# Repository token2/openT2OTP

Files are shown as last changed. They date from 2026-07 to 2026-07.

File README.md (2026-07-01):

<p align="center">
  openT2OTP
</p>

# openT2OTP — open-source programmable TOTP hardware token

An open-source **firmware + hardware reference** for a self-contained, NFC-programmable
TOTP hardware token: a small device with a segment LCD that shows a rotating
6-digit code, keeps time for 5–8 years on a coin cell (depending on model), and is provisioned over NFC using the
documented Token2 programmable-token wire protocol. Any host that implements the
protocol can provision it; the open [`token2_config.py`](https://github.com/token2/token2_config.py)
tool is one such host. The same functionality also exists as a part of the  [`keyroost`](https://github.com/framefilter/keyroost) project 
and Token2 [`NFC Burner apps`](https://www.token2.swiss/site/page/mobile-nfc-burner-apps-for-the-second-generation-single-profile-token2-programmable-tokens) for Android and iOS (to be open sourced soon).

This is mainly the **actual firmware core our original programmable TOTP tokens run
on**, and only partially a reconstruction (the original code was less elegant, we tidyed it up a bit). 
We've decided to open-source it because there is nothing to hide in how a TOTP token works: 
the security of TOTP rests on the secret seed, not on obscurity of the device, so opening the design costs nothing
and lets anyone audit, learn from, or build on it.

### A little history

This code has a long, stable lineage. The core was **finalized in 2020** and has
run our programmable tokens ever since. It has changed very little since — the
**most recent change was in 2025**, when we removed the lockout that triggered on
a wrong customer key (the handshake now simply requires re-challenging rather than
locking; see [`docs/SECURITY.md`](docs/SECURITY.md)). What's published here is
**exactly the core our current hardware runs** — same protocol, same crypto, same
behavior.
Initially, the tokens were only allowing programming the seed, as we used a regular RTC.
But later on,when the RTC with the possibility to adjust its counter became possible to source,
we managed to make programmable tokens with [`time sync`](TIMESYNC.md).

**About the name.** "openT2OTP" is the name we chose *for the open-source release*.
Internally, this firmware was developed and shipped under a different codename; we
picked a plain, descriptive public name rather than carry the internal one over. So
if the code, comments, or history feel like they predate the "openT2OTP" label —
they do. The name is new; the core is not.

---

## ⚠️ Read this first: TOTP is not phishing-resistant

**TOTP (the 6-digit code) does not protect you from phishing.** A convincing fake
login page can ask for your code and replay it to the real site within the 30-second
window. The code has no idea *which* website it's being typed into, so it can't tell
a real site from a fake one.

If you need real phishing resistance, **use a FIDO2 / WebAuthn security key instead.**
FIDO2 cryptographically binds each login to the real site's origin, so a phished
credential is useless to an attacker. Token2 also open-sources FIDO2 work — prefer
that for any account that supports security keys.

Use this TOTP token when a service only supports TOTP, or as a convenient second
factor where you accept the phishing trade-off. It is **not** a substitute for a
FIDO2 key.

See [`docs/SECURITY.md`](docs/SECURITY.md) for the full threat model.

---

## What's in here

```
firmware/     portable C firmware (protocol + SM4 + TOTP + segment-LCD driver)
hardware/     LCD wiring, BOM, PCB floorplan, antenna & casing notes
docs/         protocol reference, security model, porting guide
```

- **Firmware** — implements the device side of the Token2 single-profile TOTP
  wire protocol (the ISO 7816 APDUs, SM4 handshake, MAC, seed and config writes),
  plus RFC 6238 TOTP generation and a segment-LCD display driver. It interoperates
  with any conformant host; hardware-agnostic C, ported by filling in a small HAL.
- **Hardware** — a reference design built around an MCU with an integrated
  segment-LCD controller and RTC, an NFC front-end, and a coin cell. Keyfob-dongle
  form factor as the main target, card as a documented variation.

The casing and board outline here are **deliberately our own** — this is a
functional reference, not a clone of anyone's industrial design.

## Verified, not just written

Every cryptographic and framing claim in the firmware is checked against a
published test vector or an exact round-trip:

```
cd firmware
make test     # full Token2 wire-protocol session       -> ALL TESTS PASSED
make kat      # SM4 vs GM/T 0002 known-answer test        -> PASS
make totp     # TOTP vs RFC 6238 test vectors             -> PASS
make seed     # seed framing round-trips (all 1..63 lens) -> PASS
make slcd     # segment-LCD driver renders digits         -> PASS
make all      # everything
```

You need only a C compiler (`gcc`/`clang`) and `make`.

## Quick start

1. **Read the firmware** — start at [`firmware/README`](firmware/README.md) for the
   protocol implementation, then [`docs/PROTOCOL.md`](docs/PROTOCOL.md) for the wire
   format.
2. **Read the hardware reference** — [`hardware/HARDWARE.md`](hardware/HARDWARE.md)
   covers the LCD, wiring, BOM, and PCB design.
3. **Port to your target** — implement the HAL in
   [`docs/PORTING.md`](docs/PORTING.md) (RTC, NVM, RNG, LCD segment map).
4. **Provision a token** — use [`token2_config.py`](https://github.com/token2/token2_config.py) 
   over NFC/PC-SC to write a seed and configuration.

## On sourcing components

The BOM lists **mainstream, easy-to-source example parts** (a Microchip SAM L22
MCU, a standard NFC front-end, a transflective segment LCD, a CR2032). You can
build the reference with off-the-shelf parts from any distributor.

**We ordered components manufactured specifically for this code to run on** — the
exact parts our production tokens use. They're proven, but **not always easily
sourceable** (some are factory-tailored equivalents of a mainstream component).
Our **research suggests standard off-the-shelf components should work as well**, so
the BOM lists mainstream, buy-anywhere equivalents as examples, not requirements:
anything with an integrated segment-LCD controller, an RTC, and enough flash should
do. If small changes are needed to run on a particular off-the-shelf part, **we'll
update the design — and community updates, or even just reports of such
incompatibilities, are very welcome.**

## Board layout

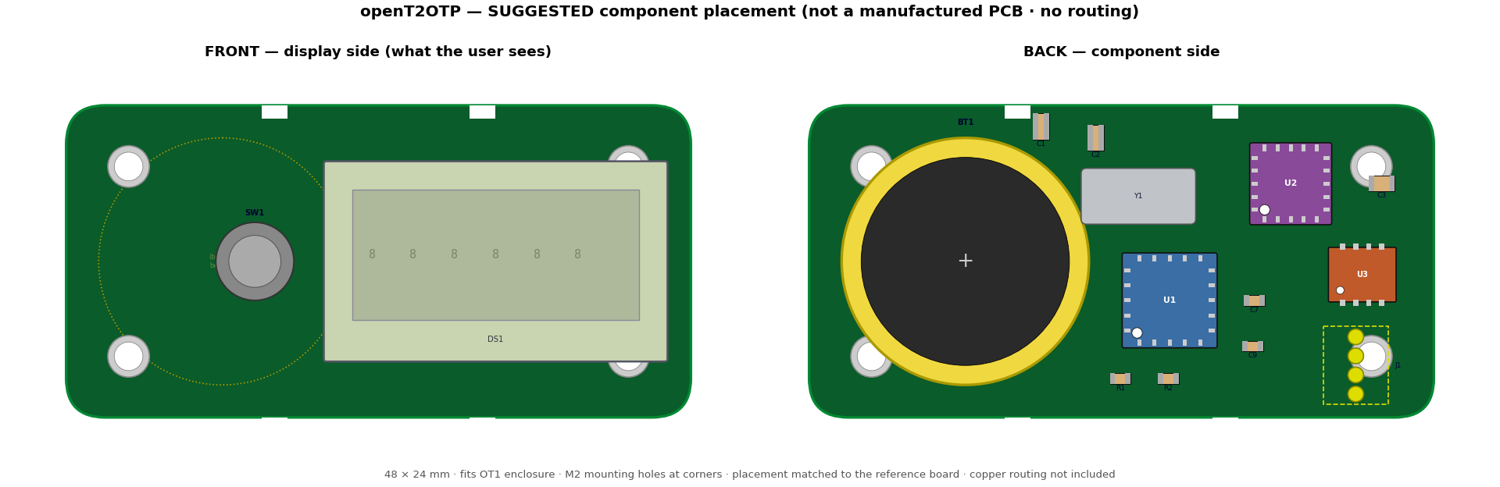
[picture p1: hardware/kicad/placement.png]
openT2OTP suggested component placement


*Suggested component placement — an illustration, not a manufactured PCB or a
routed board. See [`hardware/kicad/README.md`](hardware/kicad/README.md) for
what this is and isn't.*

## License

- **Firmware:** MIT — see [`LICENSE`](LICENSE).
- **Hardware documentation & design:** CERN-OHL-P v2 — see
  [`hardware/LICENSE-HARDWARE`](hardware/LICENSE-HARDWARE).

## Contributing

Issues and PRs welcome — see [`CONTRIBUTING.md`](CONTRIBUTING.md). Good first areas:
additional glass pin-maps, a routed KiCad PCB for the reference board, and reports
of any off-the-shelf components that need small tweaks to run the core (see the
sourcing note).

## Provenance

This is the **real device-side firmware from our programmable TOTP tokens**,
implementing the **Token2 single-profile programmable TOTP wire protocol**. The
protocol and a reference host are published openly at
[`token2_config.py`](https://github.com/token2/token2_config.py) (see its
`PROTOCOL.md`); that tool is one conformant host. The core here was finalized in
2020, last changed in 2025 (wrong-key lockout removed), and is what our current
hardware runs.

## P.S. Also available: programmable cards

The same openT2OTP firmware core also runs on our programmable TOTP **cards** — the
credit-card-format version of the token. From the code's point of view they are
identical: the same provisioning protocol, the same seed handling, the same one-time-code
generation. If you have read and trust the firmware here, it is the very same firmware on
the card.

The *hardware*, however, is a different story. A card packs the electronics into
ISO-7810 thickness using laminated inner layers, thermally bonded assembly, and custom
ultra-thin flat batteries — construction that requires specialised industrial equipment.
Unlike the keyfob reference in this repository, a card is **not something you can assemble
yourself**, and we don't publish it as a DIY design because it genuinely isn't one. The
open source here is the firmware; the card hardware is ours to manufacture.

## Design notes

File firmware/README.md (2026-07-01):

# Firmware — device-side TOTP token

> Part of the [openT2OTP](../README.md) repository. See the root README for the
> project overview and the important note that **TOTP is not phishing-resistant**
> (use FIDO2 for phishing resistance).

This is the **actual device-side firmware from our programmable TOTP tokens** —
a portable, hardware-agnostic implementation of the Token2 single-profile
programmable TOTP token **wire protocol**. Any host that speaks the protocol can
provision the device; the open `token2_config.py` is one such host, and its
`PROTOCOL.md` is the canonical spec this firmware implements. A host writes a seed
and configuration to the token over NFC/PC-SC; this firmware is what answers those
APDUs. The core was finalized in 2020 and is verified by host-side tests that
replay a full session and check the crypto against published test vectors.

> **Provenance & scope.** This is our real production core, now open-sourced —
> not a reconstruction. The "device SM4 key" in `PROTOCOL.md` is a fixed, publicly
> documented value (intentionally so — see `../docs/SECURITY.md`); anyone forking
> this for a *different* product who wants real device authentication should move
> to a per-device secret key. As-is, this is exactly what our tokens run.

## What it implements

Plain commands (CLA `0x80`, no auth):
- `0x41` get info — returns serial + on-device UTC time
- `0x4B/P1=08` get challenge — 8 random bytes
- `0xCE` auth finish — verifies `SM4(challenge ‖ 8 zero bytes)`

Secure commands (CLA `0x84`, 4-byte SM4-CBC-MAC required, auth required):
- `0xC5/P1=01` write seed — SM4-ECB body, 9797-1 padding, both the general and
  the 32-byte "extra pad block" framings
- `0xD4` write config — 19-byte plaintext TLV: display timeout, UTC clock set,
  HMAC algo (SHA1/SHA256), time step (30s/60s)

Behaviours from the spec: MAC header uses plain class `0x80` even for `0x84`
APDUs; `restricted_sync` clears the seed on config write; bad auth / locked key
returns `6983`; wrong length returns `6700`.

## Layout

```
include/  sm4.h  token2.h  token2_hal.h     public API + HAL contract
src/      sm4.c                             SM4 + protocol CBC-MAC (KAT-verified)
          token2.c                          APDU dispatcher (the firmware core)
          nfc_transport.c                   deploy shim for SE applet / MCU frontend
test/     mock_hal.c test_main.c kat.c      host tests
Makefile
```

## Build & test (host)

```
make test     # replays a full host session against the core -> ALL TESTS PASSED
make kat      # SM4 vs GM/T 0002 known-answer test -> PASS
```

The core (`src/sm4.c`, `src/token2.c`) has no host dependencies beyond the four
HAL functions in `token2_hal.h`. Cross-compile those two files with your target
toolchain and supply a real HAL.

## Porting: the HAL you must provide

| Function | Responsibility | On a secure element |
| --- | --- | --- |
| `hal_rtc_get/set` | UTC seconds, set by config cmd | external low-power RTC (SE usually has none) |
| `hal_nvm_read/write` | tamper-resistant store for seed+config | SE protected EEPROM/flash |
| `hal_rng` | 8-byte challenge | certified on-die TRNG (never a clock-seeded PRNG) |
| `hal_ct_memcmp` | constant-time compare | SE crypto-lib helper |

## Hardware recommendations

The protocol has three hard requirements that drive the part choice:
**(1) contactless ISO 14443-4 (NFC Type-4) card emulation answering raw APDUs
with no applet SELECT, (2) SM4** (the GB/T 32907 cipher — not AES), and
**(3) a timekeeping source** for TOTP.

### Important constraint: SM4 availability

Mainstream JavaCard/JCOP secure elements (e.g. NXP JCOP 4.5 on P71) expose
AES / 3DES / RSA / ECC / SHA through the JavaCard crypto API but **do not expose
SM4** as a standard primitive; JCOP lists AES, 3DES, RSA, ECC and Korean SEED,
not SM4. So on a certified SE you have two realistic routes:

- **A native SM4 execution path.** NXP JCOP 4.5 P71 ships *SecureBox*, a native
  C sandbox inside the secure enclave for exactly the algorithms the JavaCard
  API lacks. Compile `sm4.c` into a SecureBox module and call it from the
  applet. This keeps the key and cipher inside the certified boundary. Requires
  an NXP SecureBox NDA/toolchain (partners like Cryptnox do this commercially).
- **Software SM4 in the applet.** Run `sm4.c` as plain applet bytecode. Simplest
  to build; the seed still lives in SE-protected EEPROM, but the SM4 operation
  itself isn't hardware-accelerated or side-channel-hardened. Acceptable for a
  reference/interop token, not for a high-assurance product.

### Option 1 — Certified secure element (closest to the real product)

- **NXP JCOP 4.5 on P71 (SmartMX3)** — ARM SC300 + FAME3 crypto coprocessor,
  Java Card 3.0.5/3.1, GlobalPlatform 2.3.x, dual-interface (contact +
  contactless up to 848 kbit/s), EAL6+ class hardware, PUF-backed identity.
  Register your applet with the **default-selected** privilege so the card
  routes APDUs to it without a SELECT AID — that is what lets a host like `token2_config.py`
  talk to it directly, matching the "no applet SELECT" posture in the protocol.
  SM4 via SecureBox as above.
- **Infineon SLE78 / SECORA ID** or **Samsung S3K** are equivalent-class
  alternatives if you prefer their toolchains; same SM4 caveat applies.

Pros: real tamper resistance, certified TRNG, protected key store, exactly the
device category Token2 ships. Cons: NDA-gated SDKs, needs an external RTC.

### Option 2 — Secure MCU + NFC frontend (fastest to prototype, fully open)

- **MCU:** an Arm Cortex-M with on-chip AES/crypto and secure storage, e.g.
  **STM32L5 / U5** (TrustZone-M, on-chip RTC, low power) or **NXP LPC55S69**
  (TrustZone, PUF, casper crypto). The on-chip RTC satisfies requirement (3)
  directly; run `sm4.c` in software (cheap on M33).
- **NFC frontend in card-emulation:** **ST25DV** (dynamic NFC tag with I²C, if
  you drive the tag memory) or a full CE-capable controller like **NXP PN7160 /
  PN5180** or **ST ST25R3916** presenting an **ISO-DEP (14443-4)** endpoint.
  ISO-DEP is block-based (T=1); feed each deblocked APDU straight to
  `nfc_on_apdu()` — no `61 XX`/`6C XX` handling needed (that's only for T=0
  contact readers).

Pros: no NDA, open toolchain, on-chip RTC, easy to debug over the same PC/SC
path a conformant host uses. Cons: not certified tamper-resistant; a discrete secure
element (e.g. **ATECC608** / **NXP SE050** / **Microchip TA100**) can be added
over I²C to hold the seed if you want a protected key store — note those provide
AES/ECC, so SM4 still runs on the MCU.

### Option 3 — Add a dedicated secure element to Option 2

Pair the MCU with **NXP SE050** or **Microchip ATECC608B** purely as a protected
key/seed vault and TRNG source (map `hal_nvm_write` for the seed and `hal_rng`
to it), while SM4 and the APDU logic stay on the MCU. Good middle ground:
open toolchain, hardware-protected secrets.

## Deployment shim

`src/nfc_transport.c` shows the two integration points:
`nfc_on_activate()` (call at power-up → `token2_init()`) and
`nfc_on_apdu(cmd, len, resp, cap)` (call per received APDU). For an SE applet,
call `token2_process_apdu()` from `process(APDU)`; for an MCU, call it from your
ISO-DEP receive callback.

## Security notes (read before shipping anything)

- The device SM4 key is **fixed and public** in the protocol, so device
  authentication only proves the host knows a published constant — it is not a
  real secret. Any product reusing it has no meaningful anti-cloning or
  anti-tamper authentication at the protocol level. A real deployment should
  move to a per-device key and a challenge/response the attacker can't precompute.
- Keep the seed inside the secure boundary (SE EEPROM or a discrete SE); never
  expose a read-seed command (the protocol has none — preserve that).
- Use a certified TRNG for the challenge; a predictable challenge lets a
  recorded `SM4(challenge‖0)` be replayed.
```

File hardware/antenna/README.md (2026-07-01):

# NFC antenna — design, geometry & tuning

The token is read and provisioned over NFC at **13.56 MHz** (ISO 14443). The
antenna is a **PCB copper loop** around the board perimeter — no antenna "part"
in the BOM, only etched copper plus two tuning capacitors (C1/C2).

## Files here

| File | What it is |
| --- | --- |
| `coil.md` | Reference coil geometry for the keyfob outline (turns, width, spacing, keep-out). |
| `tune.py` | Calculator: given the measured loop inductance, prints the matching capacitance for 13.56 MHz. |

## Quick tune

```
# after measuring the fabricated coil (e.g. 2.5 uH):
python3 tune.py -L 2.5u
```

Fit the nearest C0G/NP0 E12 value across C1/C2, then trim on the bench against a
VNA resonance dip or by maximising reader read-range. Re-check with the shell
closed and battery fitted — both shift resonance.

## Rules that must hold

1. **No copper, no battery, no metal inside the loop** — it detunes the coil and
   kills read range. Battery goes on the back, outside the loop footprint.
2. **Via-stitch the corners** so top/bottom turns add in series.
3. **Keep the LCD zebra zone clear** of the coil.
4. **Symmetric terminals** back to C1/C2 near the NFC front-end.

## Vendor references

Start from your NFC front-end vendor's antenna design guide and tuning
spreadsheet (ST and NXP publish these for their 13.56 MHz front-ends) and adapt
the outline to the keyfob shape rather than computing the coil from scratch.

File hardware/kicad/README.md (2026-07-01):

# KiCad — reference schematic & netlist

This directory holds a **connectivity schematic** for the openT2OTP reference
board, generated from the documented design. It is not a routed PCB — it gives
you the correct components and nets so you can drop in real footprints and lay
out the board.

## Files

| File | What it is |
| --- | --- |
| `openT2OTP.kicad_sch` | Self-contained KiCad 7 schematic (symbols embedded; opens with no external libraries). Every component is a labeled block; nets are expressed as global labels. |
| `openT2OTP.net` | KiCad-format netlist — the electrical source of truth (27 nets, 0 dangling). |
| `gen_schematic.py` | The schematic generator. Edit the `COMPONENTS` and `NETS` tables and regenerate. |
| `openT2OTP.kicad_pcb` | KiCad 7 PCB with the **board outline, mounting holes, and component placement** sized to fit the OT1 enclosure. **Placement only — not routed** (see below). |
| `gen_pcb.py` | The PCB generator. Board geometry (48×24 mm, 4× M2 holes at ±19.2/±7.3 mm) is derived from the OT1 STEP enclosure. |
| `gen_gerber.py` | Exports the mechanical Gerber + drill (outline + mounting holes). |
| `gerbers/` | Fabricable **board-outline** Gerber (`Edge_Cuts.gbr`) and Excellon drill (`PTH.drl`). Copper layers are absent by design — route first. |
| `placement.png` | **Suggested placement diagram** (see below) — an illustration, not a manufactured PCB. |
| `draw_placement.py` | Renders `placement.png` from the `.kicad_pcb`. |

## About `placement.png` — read this so it isn't misunderstood

`placement.png` is a **suggested component-placement diagram**. It shows where each
part would sit on a 48×24 mm board that fits the OT1 enclosure, with the arrangement
matched to the real reference board (battery clip at one end, IC cluster at the
other, LCD and button on the front).

**It is a drawing, not a photograph of a real board, and not a fabricable PCB.**
Specifically:

- The component shapes (QFNs, coin cell, LCD, crystal) are **illustrations** drawn
  to approximate size, not real vendor footprints.
- There is **no copper routing** — no traces, no ground plane, no vias. A real board
  needs all of that, done in KiCad with real footprints and DRC.
- A **Gerber/PCB never contains components anyway** — Gerbers describe only the bare
  board (copper, mask, silk, drill). The chips you see on a physical board are placed
  after manufacturing and never appear in Gerber files. So a "PCB image with chips on
  it" only comes from a **3D render of a fully-routed board**, which is a later step.

Use this diagram to understand and communicate the layout. To get to a board that
looks like the reference hardware: assign real footprints in `openT2OTP.kicad_pcb`,
route it, run DRC, then use KiCad's 3D viewer for a populated render and export the
full Gerber set for fab.

## The PCB: what's real and what isn't

The `.kicad_pcb` and the `gerbers/` are **mechanically real and honest about their
limits**:

- **Real & fabricable now:** the 48×24 mm rounded board outline and the four M2
  mounting holes at the enclosure's boss positions (±19.2, ±7.3 mm). A fab can cut
  and drill this exact blank and it will fit the OT1 case. The outline Gerber is a
  closed, dimension-checked profile.
- **Real placement:** all 15 components from the netlist are placed with courtyards,
  overlap-checked, front/back split (LCD on the front face; MCU, NFC, secure
  element, crystal, coin cell, passives, SWD on the back).
- **NOT done — you must do this in KiCad:** copper routing, the ground pour, via
  stitching, and especially the **13.56 MHz antenna matching**. The perimeter loop
  on `F.Cu` is placeholder geometry; measure the fabricated coil and retune with
  `../antenna/tune.py`. Run DRC, then export the full copper/mask/silk/paste Gerber
  set for production. **Do not send the current state to fab as a finished board.**

## Regenerate

```
python3 gen_schematic.py > openT2OTP.kicad_sch   # schematic + netlist
python3 gen_pcb.py       > openT2OTP.kicad_pcb   # outline + holes + placement
python3 gen_gerber.py                            # mechanical gerbers -> gerbers/
```

The net table in `gen_schematic.py` is validated to have no single-pin
(dangling) nets. See `../PINMAP.md` for the human-readable pin assignment.

## How to take this to a board

1. Open `openT2OTP.kicad_sch` in KiCad 7+.
2. Replace each generic block with the real library symbol + footprint for your
   chosen part (SAM L22 TQFP64, ST25R3916 QFN32, SE050, the LCD glass zebra
   footprint, 0402/0603 passives, CR2032 holder).
3. Keep the nets identical to `openT2OTP.net`.
4. Lay out the PCB per `../HARDWARE.md` (keyfob floorplan) and
   `../antenna/coil.md` (perimeter antenna + keep-out).
5. Design your own board outline and silkscreen — see `../CASING.md`.

## What this is not

- The `.kicad_pcb` is **placement, not a routed board** — no copper traces, no
  ground pour, no tuned antenna. Routing and DRC are yours to do in KiCad.
- Not tied to specific footprints — symbols and placement blocks are generic by
  design, so the netlist stays valid whatever exact parts you source. Swap in real
  vendor footprints before routing.

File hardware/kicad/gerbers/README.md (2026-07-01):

# Gerbers — board outline + drill only

These files define the **mechanical** board only:

- `openT2OTP-Edge_Cuts.gbr` — the 48 x 24 mm rounded board outline (RS-274X).
- `openT2OTP-PTH.drl` — Excellon drill: 4 x M2 (2.2 mm) mounting holes at the
  OT1 enclosure boss positions (+/-19.2, +/-7.3 mm).

They let a fab cut and drill the correctly shaped blank that fits the OT1 case.
**Copper layers are intentionally absent** — the board is not yet routed. Route
it in KiCad from `../openT2OTP.kicad_pcb`, run DRC, then export the full Gerber
set (copper, soldermask, silk, paste) for production.

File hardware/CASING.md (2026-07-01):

# Casing & industrial design

The enclosure and board outline in this reference are **deliberately our own**.
This repository open-sources how a TOTP token *works* — the firmware, the wire
protocol handling, the electrical design — not any particular product's *look and
feel*. The industrial design (shell shape, button placement, silkscreen, colours,
proportions) is intentionally distinct from other vendors' tokens to avoid trading
on anyone's trade dress or design IP.

If you fork this, keep that separation in mind: reuse the electronics and firmware
freely under their licenses, but design your own housing rather than copying an
existing product's appearance.

## Reference form factor: keyfob dongle

Our main reference is a **keyfob dongle** with:
- a segment LCD window at one end,
- a single power/show button at the other,
- a key-ring tab on one side,
- a two-part snap or ultrasonically-welded shell.

Chosen because it's the most buildable: a rigid board with vertical room for a
replaceable coin-cell holder, a tactile button, and a generous perimeter antenna.
See [`HARDWARE.md`](HARDWARE.md) §0 for the dongle-vs-card trade-offs.

**Distinct design cues** (make your own choices — these are just ours):
- an asymmetric outline rather than a plain rounded rectangle,
- button and LCD arranged along the long axis,
- our own silkscreen pattern and wordmark placement.

## Card variation

A card variant is documented as a variation (same schematic, thinner stack-up,
printed antenna, sealed cell). If you build a card, again: use your own card
artwork and outline, not a copy of an existing product's card face.

## Mechanical checklist

- LCD window aligned to the glass active area; light pipe or plain window (no
  backlight needed for a transflective display).
- Button plunger reaches the PCB switch with the shell closed.
- Coin-cell access: a hatch for the keyfob (replaceable) or a sealed pocket for
  the card.
- Antenna keep-out respected inside the shell — no metal foils or coatings over
  the coil.
- Housing holds the LCD zebra strip under compression against the PCB pads.

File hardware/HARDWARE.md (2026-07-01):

# TOTP token — LCD, wiring, BOM & PCB design

This extends the device-side firmware with the **display and board design** for a
self-contained programmable TOTP token: a device that shows a 6-digit code on a
segment LCD, keeps time on a coin cell for 5–8 years (model-dependent), and is
provisioned over NFC by any host implementing the Token2 programmable-token
protocol.

The whole approach is modeled on how commercial tokens (and the open-source
Sensor Watch) actually do it: a **raw segment-LCD glass driven directly by an
MCU that has a built-in LCD controller** — no separate display driver, always-on
at microamps, years on one cell.

## 0. Form factor: keyfob dongle (main) vs card (variation)

This matches the real Token2 line, which ships both a **keyfob dongle** (the
C302 style) and a **card** token. Electrically they are the *same design* — 6-digit
segment LCD, one power/show button, coin-cell-class power, NFC programming with no
port. The only differences are mechanical: antenna size, battery, and rigidity.

**Main target: the keyfob dongle (C302-style).** It's the easier and more
prototype-friendly build:
- A normal **rigid FR-4 board (~1.6 mm)** with vertical room for a proper tactile
  button and a **user-replaceable CR2032 holder** on the back.
- A **larger perimeter antenna loop** → better NFC read range and easier tuning.
- A molded two-part case with a key-ring tab.

**Variation: the card.** Same schematic, harder mechanicals:
- Card body is ~0.8 mm, so it needs a **flex or ultra-thin rigid-flex PCB** and a
  **printed/embedded antenna** in a smaller area.
- Powered by a **soldered thin coin/pouch cell** (e.g. a thin CR-class cell), not
  a holder — which is why production card tokens are **sealed and disposable** when
  the battery is exhausted.
- Assembly is typically laminated rather than a snap case.

Everything below (MCU, LCD, firmware, BOM) is shared; the two "PCB design"
subsections at the end call out what changes for the card.

---

## 1. Why a segment LCD (not OLED / TFT / LED)

| Option | Idle current | Always-on | Fits a card | Verdict |
| --- | --- | --- | --- | --- |
| **Segment LCD (transflective TN)** | ~1–5 µA | yes | yes | **Chosen** |
| OLED | mA-class when lit | no | thick | too power-hungry |
| TFT | tens of mA + backlight | no | thick | far too power-hungry |
| LED 7-seg | mA even dimmed | no | yes | drains a coin cell in days |

A TOTP token must hold the display readable while sipping current from a CR2032
(~225 mAh). Only a reflective/transflective segment LCD does that. The trade-off
is that a segment LCD can only show fixed shapes — which is fine, we only need
digits 0–9.

At a segment-LCD idle draw of ~1–5 µA, a ~225 mAh CR2032 lasts on the order of
**5–8 years** (225 mAh / a few µA ≈ tens of thousands of hours), which is the
service life real programmable TOTP tokens quote. Exact life depends on the
model: display duty, how often the code is shown, the RTC/MCU sleep current, and
self-discharge of the cell. Lower-power sleep modes and a smaller display push
toward the upper end; a larger display or frequent button use toward the lower.

---

## 2. How the LCD wires to the MCU

A multiplexed segment LCD is a grid of **COM (backplane)** lines crossing
**SEG (segment)** lines. Each bar of each digit is one pixel that lights when its
COM/SEG intersection is driven. The MCU's SLCD peripheral generates the AC
drive waveforms (bias voltages, frame-inverted so there's **no net DC** — DC
permanently damages LCD glass).

For a **6-digit, 7-segment** display = 42 segments. With a common **1/4-duty**
glass:
- 4 COM lines
- ⌈42 / 4⌉ = **11 SEG lines**
- **15 MCU pins total**, all from the SLCD peripheral.

The glass does **not** solder to the board. It connects by either:
- a **zebra strip** (elastomeric connector) pressed between glass and PCB pads by
  the housing, or
- a **heat-seal FPC tail** bonded to the board.

Wiring summary:

```
SAM L22 SLCD pins  ──►  COM0..COM3      ─┐
                   ──►  SEG0..SEG10     ─┴─► zebra strip ─► LCD glass
LCD bias caps      ──►  CAPL/CAPH, VLCD reservoir caps (per datasheet)
```

The SAM L22 has an internal charge pump / bias generator, so the only external
LCD parts are a few small bias reservoir capacitors (the datasheet's LCD section
lists the exact values). No contrast pot, no driver IC.

**Segment-to-pin mapping** is defined by the *glass* datasheet: it gives a pinout
table listing, for every segment, which COM and SEG pin it sits on. You transcribe
that table into `hal_slcd_set_digit()` (in the firmware). The portable font and
digit logic live in `firmware/src/slcd.c`; only the COM/SEG bit placement is board-specific.

---

## 3. Recommended hardware

### 3.1 MCU — the linchpin

**Microchip SAM L22 (ATSAML22N18A)** — 32-bit Cortex-M0+, and critically it
integrates:
- a **segment-LCD controller** (up to 48 SLCD pins / 320 segments — far more than
  our 15),
- a **32-bit RTC** (the TOTP time base),
- **AES**, ample flash/SRAM,
- ultra-low-power sleep modes measured in **µA**.

This is the same class of part (SAM L22) used in ultra-low-power always-on
segment-LCD designs that run for years on a coin cell. It collapses MCU + LCD
driver + RTC into one chip, which is exactly what you want in a token.

> SM4 note (from the protocol work): the SAM L22's AES block does **not** do SM4,
> so the SM4 used by the Token2 protocol runs in software (`firmware/src/sm4.c`). It's
> cheap on an M0+ and only runs during the rare NFC programming session, not on
> every display refresh.

### 3.2 Display

A **6-digit 7-segment transflective TN glass**, custom or catalog. Suppliers:
Good Display (e.g. GDC-series TN transflective segment glass), Crystalfontz,
Truly, Varitronix. For a first prototype, a catalog 6-digit static/multiplexed
TN glass with a zebra connector is the fastest path; for production you order a
custom glass with your exact digit layout and any icons (battery, lock).

### 3.3 NFC front-end

The host talks ISO 14443-4 (NFC Type-4). Two routes:
- **Discrete NFC controller in card-emulation:** NXP PN7160 / PN5180, or ST
  ST25R3916. These present a proper ISO-DEP endpoint; you feed each received APDU
  straight into `token2_process_apdu()`.
- **Passive NFC tag front-end with I²C:** ST ST25DV — simpler and lower power,
  but you drive the APDU exchange through its mailbox/energy-harvest path.

For a battery token that must answer live APDUs, a controller like the
**ST25R3916** or **PN7160** is the clean choice.

### 3.4 Optional secure element (seed vault)

The seed should live in tamper-resistant storage. Add **NXP SE050** or
**Microchip ATECC608B** over I²C purely to hold the seed and serve the TRNG;
SM4 and APDU logic stay on the MCU. (These provide AES/ECC, not SM4 — that's
fine, they're a vault, not the protocol engine.)

**This is what makes "the seed can't be extracted" true.** The wire protocol is
already write-only (no read-seed command), but on a bare MCU the seed still sits in
on-die flash and is recoverable by a determined attacker. Put it in an SE and it
never leaves the SE's protected store. Best practice: inject the seed into the SE
**marked non-exportable** and run the HMAC **inside** the SE, so the seed is never
present in MCU RAM — even compromised firmware can't read it. Our production tokens
do exactly this. See [`docs/SECURITY.md`](../docs/SECURITY.md) → "Seed protection"
for the storage-vs-extraction table (Pico/plain flash = assume extractable; SE with
non-exportable key = not extractable). Omit the SE for a hobby/demo build; include
it for anything resembling a product.

### 3.5 Timekeeping

The SAM L22 RTC runs from a **32.768 kHz watch crystal** (e.g. Epson FC-135 or
Abracon ABS07). This sets TOTP accuracy — use a crystal with a low ppm rating so
codes don't drift between programmings.

### 3.6 Power

**Keyfob (main):** **CR2032** (3 V, ~225 mAh) in a **back-side replaceable
holder**, with decoupling caps. At a few µA average the token runs about **5–8
years** on one cell (model-dependent — see §1), and the user can swap the cell.

**Card (variation):** a **soldered thin coin/pouch cell** in the ~0.8 mm budget;
no holder, so the card is sealed and replaced (not serviced) at end of life.

---

## 4. Bill of materials (single prototype)

Reference prices are indicative single-unit/small-qty (USD) and will drop sharply
at volume. Always confirm live pricing and stock at a distributor.

| # | Ref | Part | Function | Example MPN | ~Qty | ~Unit $ |
| --- | --- | --- | --- | --- | --- | --- |
| 1 | U1 | MCU w/ SLCD+RTC | brains, LCD drive, timekeeping | ATSAML22N18A | 1 | 4–6 |
| 2 | DS1 | 6-digit 7-seg TN LCD glass | display | Good Display GDC-series (or custom) | 1 | 2–5 |
| 3 | — | Zebra strip / heat-seal | glass-to-PCB contact | elastomeric connector | 1 | 0.3–1 |
| 4 | U2 | NFC controller | ISO 14443-4 card emulation | ST ST25R3916 / NXP PN7160 | 1 | 2–4 |
| 5 | U3 | Secure element (optional) | seed vault + TRNG | NXP SE050 / Microchip ATECC608B | 1 | 0.5–2 |
| 6 | Y1 | 32.768 kHz crystal | RTC time base | Epson FC-135 / Abracon ABS07 | 1 | 0.3–0.6 |
| 7 | BT1 | CR2032 holder (keyfob) | replaceable coin-cell socket | Keystone 3002 (or SMD equiv) | 1 | 0.3–0.7 |
| 8 | — | CR2032 cell | power (keyfob) / thin cell for card | any | 1 | 0.3 |
| 9 | L1 | NFC antenna | PCB copper loop (no part) | on-board etch | — | 0 |
| 10 | C1,C2 | Antenna tuning caps | match coil to 13.56 MHz | C0G/NP0, values from tuning | 2 | 0.02 |
| 11 | C3–C6 | LCD bias reservoir caps | SLCD charge-pump | X7R, per L22 datasheet | ~4 | 0.02 |
| 12 | C7–C10 | Decoupling caps | VDD rails | 100 nF / 1 µF X7R | ~4 | 0.02 |
| 13 | SW1 | Power/show button | wake + display code | tactile SMD (keyfob) / dome (card) | 1 | 0.1 |
| 14 | J1 | SWD pads/header | program & debug | 2x5 1.27 mm or test pads | 1 | 0.2 |
| 15 | — | PCB | keyfob: 2-layer FR-4 ~1.6 mm · card: flex/rigid-flex ~0.8 mm | fab | 1 | 1–3 (proto) |

**Indicative BOM total (prototype, incl. optional SE):** ~$13–28 depending on the
display and NFC controller. At volume the electronics fall well under $10.

> **Sourcing note.** We **ordered components manufactured specifically for this
> code to run on** — that's what our production tokens use, and they are proven.
> Those exact parts are **not always easily sourceable** (some are factory-tailored
> equivalents of a mainstream component). Our **theoretical and bench research
> suggests standard off-the-shelf components should work as well**, and the MPNs
> listed above are those mainstream, buy-anywhere equivalents so you can reproduce
> the design without our supply chain. They are examples, not requirements: any MCU
> with an integrated segment-LCD controller + RTC + enough flash, any 13.56 MHz
> front-end, and any transflective 6-digit glass should do.
>
> If small changes turn out to be needed to run on a particular off-the-shelf part,
> **we'll update the design** — and **community updates, and even just reports of
> such incompatibilities, are very welcome** (open an issue or PR).

---

## 5. PCB design guidance

**Main: keyfob dongle.** Rigid 2-layer FR-4, ~1.6 mm — the extra thickness gives
vertical room for a tactile button, a CR2032 holder on the back, and a two-part
molded case with a key-ring tab. The floorplan diagram above shows the placement:
LCD at one end, power button at the other, MCU + crystal central, antenna around
the perimeter. The rules that actually matter:

1. **NFC antenna = perimeter loop.** Run 3–5 turns of copper around the board
   edge on both layers, stitched with vias at the corners, to maximize the
   enclosed area (coupling scales with loop area). The keyfob's larger outline
   gives a bigger loop and better read range than the card.
2. **Antenna keep-out is sacred.** No ground pour, no battery, no large copper
   *inside* the loop — metal detunes the coil and kills read range. The coin cell
   holder goes on the back, offset outside the antenna footprint.
3. **Tune to 13.56 MHz.** The coil inductance plus C1/C2 forms the resonant tank.
   Measure the coil, compute C, then trim on the bench with a VNA / reader
   read-range test.
4. **No copper under the LCD.** Keep the zebra contact zone clean; a pour under
   the glass can cause uneven contrast and contact issues.
5. **Crystal placement.** Put Y1 close to the MCU RTC pins with a local ground
   guard; keep noisy NFC traces away from it so time doesn't jitter.
6. **MCU central**, SLCD pins fanning to the LCD pads, NFC pins to the antenna
   edge, I²C to the secure element, SWD pads accessible for programming.
7. **Decoupling** close to every VDD pin; the SLCD bias caps per the L22 datasheet
   LCD section.

**Variation: card.** Same schematic and rules, but the ~0.8 mm body forces:
- a **flex or rigid-flex PCB** instead of 1.6 mm FR-4;
- a **printed/etched antenna** in a smaller area — expect lower read range, so
  budget more care in tuning;
- a **soldered thin cell** and a **dome/membrane button** instead of a holder and
  tactile switch;
- **lamination** rather than a snap case, making the unit sealed/disposable.
Keep the same block placement, just flattened into the thinner stack-up.

**Tools:** KiCad (free) is ideal — its footprint editor handles the custom
antenna coil and LCD zebra pads. Many NFC-controller vendors publish reference
antenna designs and tuning spreadsheets; start from those rather than computing
the coil from scratch.

---

## 6. Firmware for the display path

Two new modules sit on top of the protocol core:

- **`firmware/src/totp.c`** — RFC 6238 TOTP over the stored seed (HMAC-SHA1). Verified
  against the RFC 6238 published test vectors (T=59 → `287082` for 6 digits,
  and the 8-digit `94287082` / `07081804` vectors). This turns the seed written
  into the code shown on screen (the seed written by any conformant host).
- **`firmware/src/slcd.c`** — 7-segment font + digit placement. `slcd_show_code(code, 6)`
  renders a zero-padded 6-digit code; `hal_slcd_set_digit()` (which you fill in
  from the glass pinout) writes the COM/SEG bits into the SLCD frame buffer.

Typical main loop on the MCU:

```
on wake (RTC tick or button):
    t     = hal_rtc_get()
    code  = totp_now(seed, seed_len, t, step_seconds, 6)
    slcd_show_code(code, 6)
    stay awake briefly, then slcd_blank() and deep-sleep
on NFC field detect:
    run token2_process_apdu() per APDU  (host programming session)
```

Build/verify the display math on the host:

```
cd firmware
make totp      # RFC 6238 vectors -> PASS
```

---

## 7. What's proven vs. what you finish on hardware

**Proven in this repo (host-verified):**
- Full Token2 wire protocol (auth, MAC, seed & config writes) — `make test`
- SM4 vs GM/T 0002 KAT — `make kat`
- TOTP vs RFC 6238 KAT — `make totp`

**You complete on the target:**
- The four HAL functions (RTC, NVM, RNG, constant-time compare)
- `hal_slcd_set_digit()` from your specific glass pinout
- NFC controller driver → APDU hand-off
- Antenna tuning on the bench

Everything above the HAL line is portable C that already works; the
board-specific glue is small and well-scoped.

---

## 8. Design files in this folder

- `bom.csv` — machine-readable bill of materials (importable into sourcing tools).
- `BOM.md` — the same **suggested BOM** as a readable table with reference
  designators; `kicad/bom-table.png` is a rendered version (via `kicad/draw_bom.py`).
  Example parts, not a locked BOM — substitute equivalents freely.
- `PINMAP.md` — MCU pin → net → component assignment.
- `kicad/openT2OTP.kicad_sch` — self-contained KiCad 7 connectivity schematic
  (symbols embedded; opens with no external libraries).
- `kicad/openT2OTP.net` — KiCad netlist, the electrical source of truth (27 nets).
- `kicad/openT2OTP.kicad_pcb` — PCB **outline + mounting holes + placement**, sized
  48×24 mm to fit the OT1 enclosure (4× M2 at ±19.2/±7.3 mm). Placement only — not
  routed; see `kicad/README.md`.
- `kicad/gen_schematic.py` — regenerates the schematic + netlist from the net table.
- `kicad/gen_pcb.py` / `kicad/gen_gerber.py` — regenerate the PCB placement and the
  mechanical (outline + drill) Gerbers in `kicad/gerbers/`.
- `kicad/placement.png` — a **suggested placement diagram** (illustration, not a
  manufactured PCB and not a routed board). See `kicad/README.md` for what it is and
  isn't.
- `antenna/coil.md` — reference coil geometry for the keyfob outline.
- `antenna/tune.py` — 13.56 MHz tuning-capacitor calculator.
- `CASING.md` — enclosure / industrial-design notes (deliberately our own).

> The two `.py` files here are **host-side design tools** — a schematic generator
> and an antenna calculator you run on your PC. They are not part of the device:
> the **firmware is C only** and contains no Python.

These are a **connectivity design**, not a routed board: correct parts and nets,
ready for you to add real footprints and lay out copper. See `kicad/README.md`.

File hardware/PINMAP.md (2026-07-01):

# Pin map — SAM L22 (U1) reference assignment

This maps the MCU pins to nets and peripherals for the reference board. SLCD pin
numbers are illustrative — the exact COM/SEG assignment is finalised against the
chosen LCD glass datasheet and transcribed into `hal_slcd_set_digit()` in
firmware (see `../docs/PORTING.md`).

## Power

| Net | Pins | Notes |
| --- | --- | --- |
| VDD (+3V) | VDDIN, VDDIO, VDDANA | from CR2032; decouple each with 100 nF |
| GND | GND pads | star/ground pour outside antenna keep-out |

## Timekeeping

| Net | MCU pin | To |
| --- | --- | --- |
| XIN32 | PA00 | Y1 (32.768 kHz) |
| XOUT32 | PA01 | Y1 |

## Segment LCD (SLCD peripheral)

| Function | MCU pins (illustrative) | To |
| --- | --- | --- |
| COM0..COM3 | LCD_COM0..3 | DS1 backplanes (via zebra) |
| SEG0..SEG10 | LCD_SEG0..10 | DS1 segments (via zebra) |
| LCD bias | CAPL, CAPH, BIAS reservoirs | C3..C6 per datasheet |

11 SEG + 4 COM = 15 SLCD pins for a 6-digit 7-seg glass (42 segments, 1/4 duty).

## NFC front-end (U2)

| Net | MCU pin | To |
| --- | --- | --- |
| NFC_SCK | SERCOM SPI SCK | U2 SCLK |
| NFC_MOSI | SERCOM SPI MOSI | U2 MOSI |
| NFC_MISO | SERCOM SPI MISO | U2 MISO |
| NFC_CS | GPIO | U2 CS |
| NFC_IRQ | GPIO (EIC) | U2 IRQ |
| ANT1/ANT2 | — | U2 to L1 via C1/C2 tuning |

## Secure element (U3, optional)

| Net | MCU pin | To |
| --- | --- | --- |
| SE_SDA | SERCOM I2C SDA | U3 SDA (10k pull-up R1) |
| SE_SCL | SERCOM I2C SCL | U3 SCL (10k pull-up R2) |

## User + debug

| Net | MCU pin | To |
| --- | --- | --- |
| BTN | GPIO (EIC, wake) | SW1 to GND, internal pull-up |
| SWDIO | PA31 | J1 |
| SWCLK | PA30 | J1 |
| RESET | RESETN | J1 |

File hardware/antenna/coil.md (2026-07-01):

# Reference antenna coil geometry (keyfob dongle)

This is the starting geometry for the perimeter loop on the keyfob reference
board (the floorplan in `../HARDWARE.md`). Treat it as a starting point: measure
the fabricated coil's inductance and tune with `tune.py`.

## Outline

The keyfob body is roughly:

- overall board: ~55 mm (long axis) x ~28 mm (short axis)
- rounded left end + key-ring tab (outside the antenna area)
- LCD window at the right end, power button at the left

The antenna occupies the **perimeter**, just inside the board edge, wrapping
around the LCD and component cluster.

## Coil parameters (reference, pre-tuning)

| Parameter | Reference value | Notes |
| --- | --- | --- |
| Turns (N) | 4 | on top + bottom layer, via-stitched at corners |
| Track width | 0.30 mm | balance of resistance vs area |
| Track spacing | 0.30 mm | |
| Outer loop inset | 1.0 mm from board edge | keep-out from routing/case |
| Layers | 2 (top + bottom in series) | doubles effective turns for a thin board |
| Enclosed area | maximise | coupling scales with loop area |
| Estimated inductance | ~2-3 uH (measure!) | drives the tuning-cap value |

With ~2.5 uH measured, `tune.py` gives ~55 pF total (C1=C2 ~110 pF in series).

## Rules that must hold

1. **No copper, no battery, no metal inside the loop.** Ground pour or the coin
   cell inside the antenna area detunes and kills read range. Battery goes on the
   back, outside the loop footprint.
2. **Via-stitch the corners** where the loop transitions top<->bottom so the turns
   add in series.
3. **Keep the LCD zebra zone clear** of the coil.
4. **Symmetry** helps: route the two antenna terminals back to C1/C2 near the NFC
   front-end with matched trace lengths.

## Tuning

```
# after measuring the fabricated coil, e.g. 2.5 uH:
python3 tune.py -L 2.5u
```

Then fit the nearest C0G/NP0 E12 value and trim against a VNA resonance dip or by
maximising reader read-range. Re-check with the shell closed and battery fitted —
both shift resonance.

## Vendor references

Start from your NFC front-end vendor's antenna design guide and tuning
spreadsheet (ST and NXP both publish these for their 13.56 MHz front-ends) and
adapt the outline to this keyfob shape rather than computing the coil from
scratch.

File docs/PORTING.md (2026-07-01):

# Porting guide

The firmware core is hardware-agnostic C. To bring it up on a real target you
implement a small HAL and one board-specific display map. Everything above that
line already works and is verified against published test vectors.

## 1. The HAL contract

Implement the functions declared in `firmware/include/token2_hal.h`:

| Function | Responsibility | Notes |
| --- | --- | --- |
| `hal_rtc_get()` / `hal_rtc_set()` | UTC seconds; set by the config command | back with the MCU RTC or an external low-power RTC |
| `hal_nvm_read()` / `hal_nvm_write()` | tamper-resistant store for seed + config | MCU protected flash or a discrete secure element |
| `hal_rng()` | fill the 8-byte auth challenge | use a hardware TRNG, never a clock-seeded PRNG |
| `hal_ct_memcmp()` | constant-time compare | use the SE/crypto-lib helper if available |

A working mock implementation lives in `firmware/test/mock_hal.c` — use it as a
template, but replace the RNG with a real TRNG on hardware.

## 2. The segment-LCD map

`firmware/src/slcd.c` holds a portable 7-segment font and digit logic. The only
board-specific piece is where each segment physically lives on your glass. You
provide three functions the driver calls:

```c
void hal_slcd_set_digit(int position, uint8_t seg_bits); /* write 7 bits (gfedcba) */
void hal_slcd_commit(void);                              /* latch frame buffer */
void hal_slcd_blank(void);                               /* all off (sleep) */
```

**Building `hal_slcd_set_digit()`:**

1. Open your LCD glass datasheet. It has a pinout table mapping every segment
   (digit N, segment a..g) to a **(COM, SEG)** pin pair.
2. For each of the 7 bits in `seg_bits`, set or clear the matching bit in your
   MCU's SLCD frame buffer at the right (COM, SEG) location.
3. On the SAM L22 this means writing the SLCD `LCDDATAx` registers; on another
   MCU with an LCD controller, the equivalent frame-buffer registers.

The mapping is pure transcription from the datasheet table — no cleverness. Once
`make totp` passes on the host and your map is correct, the right digits appear.

## 3. NFC transport

`firmware/src/nfc_transport.c` is the integration shim:

- Call `nfc_on_activate()` once at power-up / field activation → runs `token2_init()`.
- Call `nfc_on_apdu(cmd, len, resp, cap)` for every received command APDU → returns
  the response APDU.

Wire it to your NFC front-end's ISO-DEP (ISO 14443-4) receive path. Because the
host sends **no applet SELECT**, answer APDUs directly on the basic channel after
activation. ISO-DEP is block-based (T=1), so you don't need the `61 XX` / `6C XX`
continuation handling that only applies to T=0 contact readers.

## 4. Main loop sketch

```
on wake (RTC tick or button press):
    t    = hal_rtc_get()
    code = totp_now(seed, seed_len, t, step_seconds, 6)
    slcd_show_code(code, 6)
    stay awake briefly, then slcd_blank() and deep-sleep

on NFC field detect:
    nfc_on_activate()
    loop: nfc_on_apdu(...) per received APDU   (host provisioning session)
```

## 5. Verify as you go

- `make test` / `make kat` / `make totp` / `make seed` / `make slcd` (or
  `make all`) must pass on the host before you flash.
- `make slcd` renders the digits as ASCII art — a quick way to sanity-check your
  font/segment intent before wiring real glass.
- After flashing, provision over NFC with any conformant host (e.g. `token2_config.py`) and confirm the
  displayed code matches a soft TOTP app seeded with the same secret.

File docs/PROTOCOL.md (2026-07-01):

# Wire protocol reference

The device firmware in this repo answers the **Token2 single-profile programmable
TOTP token** wire protocol. The canonical, authoritative specification is the
`PROTOCOL.md` published with the host configurator:

> https://github.com/token2/token2_config.py/blob/main/PROTOCOL.md

This page is a short orientation so you can read the firmware; always defer to the
canonical spec for exact byte layouts.

## Transport

- NFC Type-4 / ISO 7816 APDUs over a contactless (or contact) PC/SC reader.
- **No applet SELECT** — the token answers APDUs directly after activation.
- ISO-DEP (block-based) contactless; T=0 continuation only matters on contact
  readers.

## Cryptographic primitives

- **SM4** (GB/T 32907) — encrypts the seed and the auth response, and provides the
  per-command MAC. Implemented in `firmware/src/sm4.c`, verified against the
  GM/T 0002 known-answer test.
- The protocol uses a **single fixed device key** (documented in the canonical
  spec). See [`SECURITY.md`](SECURITY.md) for why that matters.

## Command families

**Plain (CLA `0x80`, no auth):**
- get info (serial + on-device UTC time)
- get challenge (8 random bytes)
- auth finish (verify `SM4(challenge ‖ 8 zero bytes)`)

**Secure (CLA `0x84`, requires auth + a 4-byte SM4-CBC-MAC):**
- write seed (SM4-ECB body, ISO/IEC 9797-1 padding)
- write config (plaintext TLV: display timeout, UTC clock, HMAC algo, time step)

The firmware's dispatcher (`firmware/src/token2.c`) implements all of these and is
exercised end-to-end by `firmware/test/test_main.c` (`make test`).

## TOTP generation

Once a seed and config are written, the device generates codes per **RFC 6238**
(`firmware/src/totp.c`, verified against the RFC's published test vectors) and
shows them on the segment LCD.

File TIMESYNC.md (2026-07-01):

# Time synchronization in openT2OTP, an example of implementation

How the token keeps time, what "sync" actually means, and how the abstract
`hal_rtc_get()` / `hal_rtc_set()` calls map to real RTC hardware.

## The model in one sentence

At provisioning the host sends one **absolute** UTC timestamp; the firmware writes
it into the RTC once, and from then on the **RTC hardware** — not the firmware —
increments that value by one every second. TOTP codes are computed from whatever
the RTC has counted up to.

## Set once, then the hardware counts

Time is a single 32-bit Unix-seconds value, reached only through two HAL calls
([`firmware/include/token2_hal.h`](../firmware/include/token2_hal.h)):

```c
uint32_t hal_rtc_get(void);            /* seconds since the UNIX epoch, UTC */
void     hal_rtc_set(uint32_t unix_seconds);
```

**Setting time** happens in the config command
([`cmd_config` in `firmware/src/token2.c`](../firmware/src/token2.c)): the host's
UTC arrives as 4 big-endian bytes in the TLV, the firmware assembles it into a
local `utc` variable, and calls `hal_rtc_set(utc)`. That is the whole write path.
The `utc` local is transient — it exists only to pass the value into the RTC; the
firmware keeps **no** timestamp of its own (there is no time field in the persisted
state struct `token2_state_t`).

**Using time** happens whenever a code is generated: the firmware calls
`hal_rtc_get()` and feeds the result to TOTP, which computes
`counter = unix_time / step` and then `HMAC(seed, counter)`
([`totp_now_algo` in `firmware/src/totp.c`](../firmware/src/totp.c)).

So the value the firmware reads is `programmed_timestamp + seconds_elapsed`, where
the elapsed part is produced entirely by the RTC ticking on its 32.768 kHz crystal.
The firmware never adds a base and an offset — it reads one already-accumulated
number.

## What "time adjustment" means

There is no incremental "adjust by N seconds" operation. Correcting drift is just
doing the absolute set again with the current true time: send the config command
with the correct UTC, `hal_rtc_set` overwrites the counter, and error starts
re-accumulating from zero.

Note the security coupling: by default (`restricted_sync = 1`) a config/time write
**also clears the seed**, so on a standard token a field time-fix is effectively a
re-provision (seed + time together). Some models (e.g. C302i) relax this to allow a
standalone time re-sync without wiping the seed — see
[`SECURITY.md`](SECURITY.md) for that trade-off.

## Where the counter actually lives

Nowhere in this repository. `hal_rtc_get` / `hal_rtc_set` are **declarations**; the
core calls them but never implements them. The body is supplied per platform:

- **Test build:** a mock in `firmware/test/mock_hal.c` stores it in a plain global
  (`g_rtc`) so tests run on a PC. It does not tick.
- **Real hardware:** the port writes an actual RTC register — either an on-chip RTC
  (e.g. a SAM L22's 32-bit `COUNT`) or an external RTC over I²C.

This is deliberate: the portable firmware stays ignorant of which RTC and which
register sit underneath.

## Concrete example: Micro Crystal RV-3028-C7 over I²C

The RV-3028-C7 is a good reference because it exposes a native **32-bit UNIX time
counter**, so `hal_rtc_set`/`get` map to a direct 4-byte write/read with no
BCD-to-epoch conversion. Its counter is driven by a digitally offset-compensated
1 Hz clock, which is what keeps long-term drift small.

Key facts (Micro Crystal RV-3028-C7 Application Manual):

- I²C address `0x52` (8-bit write address `0xA4`, read `0xA5`).
- UNIX Time counter in registers `0x1B`–`0x1E` (UNIX_TIME_0..3), **little-endian**
  (`0x1B` = bits 0–7 … `0x1E` = bits 24–31).
- The counter's increment is inhibited during an I²C write to those four registers,
  so all four bytes can be written in one transaction coherently.
- The address pointer auto-increments after each byte, so one START/STOP loads all
  four.

### Raw command

To set the clock to `0x6864F980`, write 4 bytes from register `0x1B`, LSB first:

```
START
0xA4        ; device 0x52, write
0x1B        ; register pointer = UNIX_TIME_0 (auto-increments)
0x80        ; byte 0  (bits  0-7)
0xF9        ; byte 1  (bits  8-15)
0x64        ; byte 2  (bits 16-23)
0x68        ; byte 3  (bits 24-31)
STOP
```

With Linux `i2c-tools`:

```bash
i2ctransfer -y 1 w5@0x52 0x1B 0x80 0xF9 0x64 0x68
```

### The HAL body

```c
/* RV-3028-C7: 32-bit UNIX counter at 0x1B..0x1E, little-endian, addr 0x52. */
void hal_rtc_set(uint32_t unix_seconds){
    uint8_t buf[5] = { 0x1B,                 /* start at UNIX_TIME_0 */
        (uint8_t) unix_seconds,              /* LSB first */
        (uint8_t)(unix_seconds >> 8),
        (uint8_t)(unix_seconds >> 16),
        (uint8_t)(unix_seconds >> 24) };
    i2c_write(0x52, buf, sizeof buf);        /* your platform's I2C primitive */
}

uint32_t hal_rtc_get(void){
    uint8_t reg = 0x1B, ts[4];
    i2c_write(0x52, &reg, 1);                /* set address pointer */
    i2c_read (0x52, ts, 4);                  /* read 4 bytes */
    return ((uint32_t)ts[3] << 24) | ((uint32_t)ts[2] << 16)
         | ((uint32_t)ts[1] <<  8) |  (uint32_t)ts[0];
}
```

A robust `get` reads the counter twice and retries if the two differ, to guard
against a roll-over landing mid-read.

## Caveats

- The register addresses above are specific to the **RV-3028-C7**. A different RTC
  (on-chip SAM L22 RTC, DS3231, PCF85263, …) uses the same *model* — write absolute
  seconds, let the chip count — but a different register map. Always check the part's
  datasheet.
- This file is an **illustrative reference port**, not a description of what any
  particular production device runs below the HAL line. The whole point of the HAL
  boundary is that openT2OTP does not know or care which RTC is underneath.

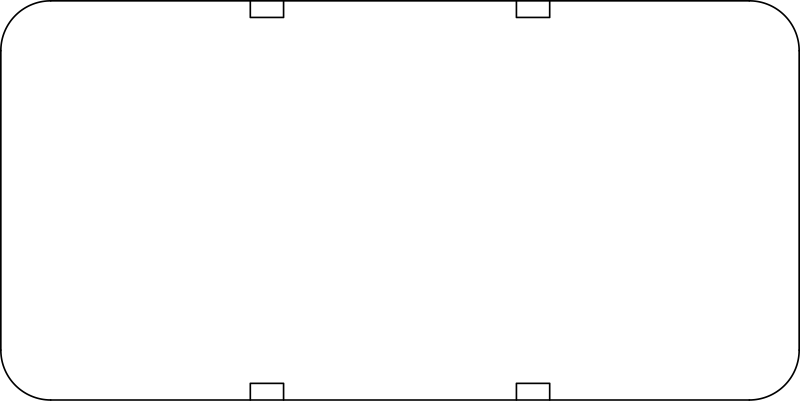
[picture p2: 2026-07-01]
hardware/kicad/gerber-outline-preview.png

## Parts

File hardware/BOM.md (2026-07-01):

# openT2OTP — Suggested Bill of Materials

> **This is a suggested / reference setup, not a locked BOM.** The parts below are
> *examples* that satisfy the design; substitute equivalents freely. The components
> used in our own production are proven but not always easily sourceable (some are
> factory-tailored equivalents), so this list points at mainstream, buy-anywhere parts.
> See the sourcing note in [`HARDWARE.md`](HARDWARE.md). Real production MPNs are not
> published. Reference designators match [`kicad/openT2OTP.net`](kicad/openT2OTP.net)
> (the netlist is a simplified connectivity model; this BOM adds the extra decoupling
> caps, the cell itself, and the zebra connector that a real build needs).

| Ref | Qty | Component | Value/Part | Example MPN | Package | Notes |
| --- | --- | --- | --- | --- | --- | --- |
| U1 | 1 | MCU with SLCD + RTC | SAM L22 | ATSAML22N18A | TQFP64 | Cortex-M0+, integrated segment-LCD controller + RTC + AES; drives LCD directly |
| DS1 | 1 | Segment LCD glass | 6-digit 7-seg TN transflective | Good Display GDC-series (or custom) | Zebra/heat-seal | 42 segments; 1/4 duty, 1/3 bias; connects via zebra strip |
| CN1 | 1 | Zebra strip / heat-seal | Elastomeric connector | - | - | Glass-to-PCB contact under housing compression |
| U2 | 1 | NFC front-end | ISO 14443-4 card emulation | ST ST25R3916 (or NXP PN7160) | QFN32 | Presents ISO-DEP endpoint; feed APDUs to firmware |
| U3 | 1 | Secure element (optional) | Seed vault + TRNG | NXP SE050 (or Microchip ATECC608B) | SOIC8/UDFN | I2C; holds seed + serves RNG. SM4 stays on MCU |
| Y1 | 1 | Crystal | 32.768 kHz | Epson FC-135 (or Abracon ABS07) | SMD 3.2x1.5 | RTC time base; low-ppm for TOTP accuracy |
| BT1 | 1 | Coin-cell holder (keyfob) | CR2032 holder | Keystone 3002 | SMD | Replaceable cell on back; card variant uses soldered thin cell |
| BAT1 | 1 | Coin cell | CR2032 3V ~225mAh | - | Coin | Power source |
| L1 | 1 | NFC antenna | PCB copper loop | - | On-board etch | 3-5 turns around perimeter; no part - etched copper |
| C1 | 1 | Antenna tuning cap | C0G/NP0 (value from tuning) | - | 0402 | Resonant match to 13.56 MHz; trim on bench |
| C2 | 1 | Antenna tuning cap | C0G/NP0 (value from tuning) | - | 0402 | Resonant match to 13.56 MHz; trim on bench |
| C3 | 1 | LCD bias reservoir cap | per L22 datasheet | - | 0402 | SLCD charge-pump; value from datasheet LCD section |
| C4 | 1 | LCD bias reservoir cap | per L22 datasheet | - | 0402 | SLCD charge-pump |
| C5 | 1 | LCD bias reservoir cap | per L22 datasheet | - | 0402 | SLCD charge-pump |
| C6 | 1 | LCD bias reservoir cap | per L22 datasheet | - | 0402 | SLCD charge-pump |
| C7 | 1 | Decoupling cap | 100nF X7R | - | 0402 | VDD decoupling near MCU |
| C8 | 1 | Decoupling cap | 100nF X7R | - | 0402 | VDD decoupling near NFC front-end |
| C9 | 1 | Decoupling cap | 1uF X7R | - | 0603 | Bulk decoupling |
| C10 | 1 | Decoupling cap | 100nF X7R | - | 0402 | VDD decoupling near secure element |
| R1 | 1 | Pull-up resistor | 10k | - | 0402 | I2C SDA pull-up (secure element bus) |
| R2 | 1 | Pull-up resistor | 10k | - | 0402 | I2C SCL pull-up (secure element bus) |
| SW1 | 1 | Power/show button | Tactile (keyfob) / dome (card) | - | SMD | Wake MCU and display code |
| J1 | 1 | SWD programming pads | 2x5 1.27mm or test pads | - | - | Program and debug; can be bed-of-nails pads |

A rendered version of this table is in [`kicad/bom-table.png`](kicad/bom-table.png).
Regenerate it with `python3 kicad/draw_bom.py`.

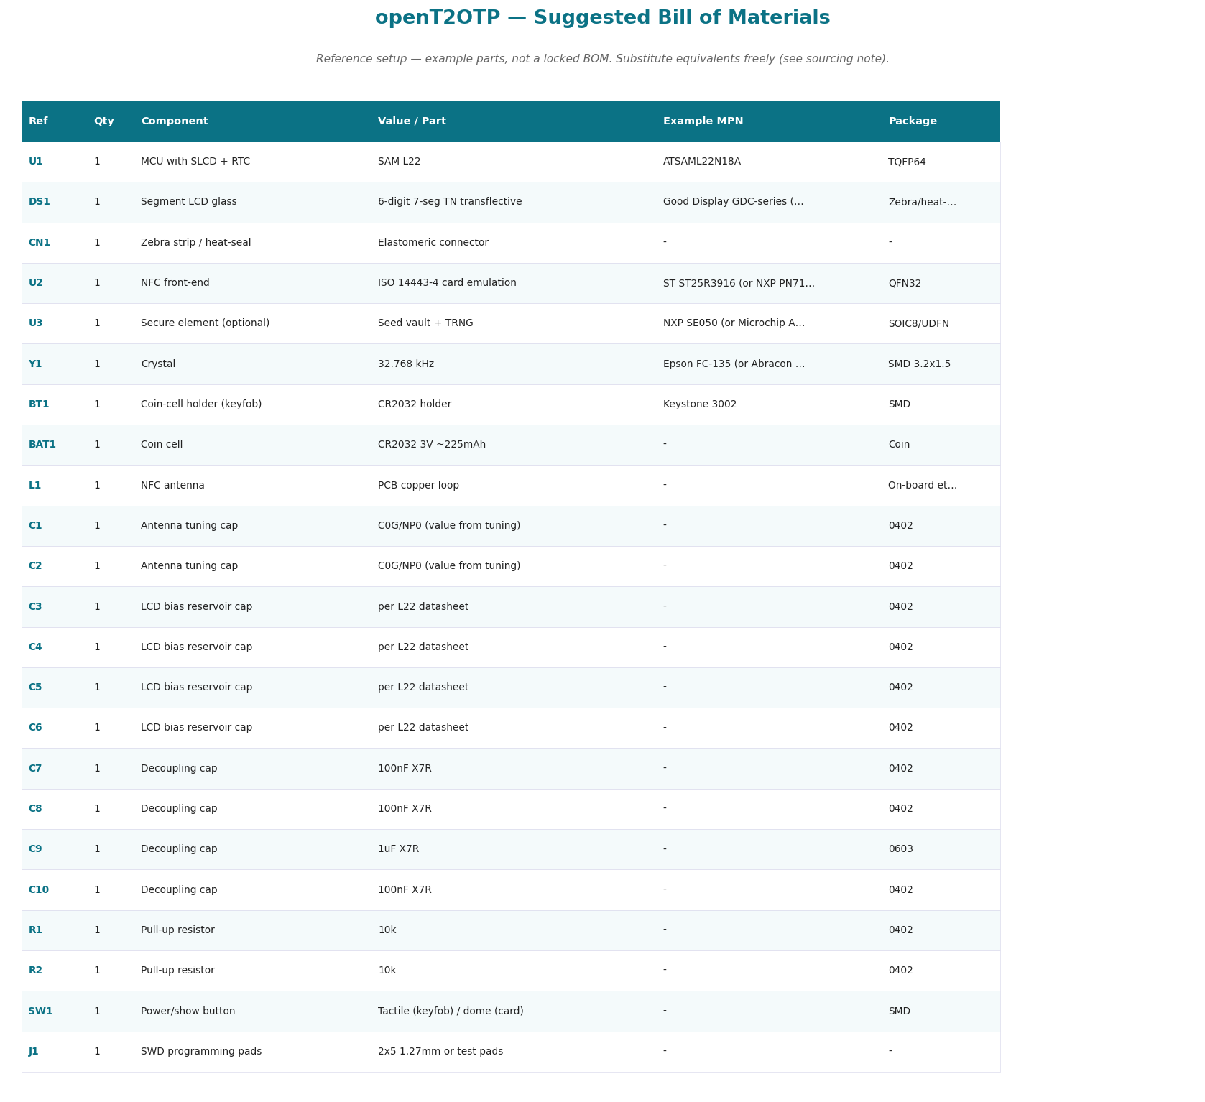
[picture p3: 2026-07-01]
hardware/kicad/bom-table.png

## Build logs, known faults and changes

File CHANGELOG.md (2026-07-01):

# Changelog

All notable changes to this project are documented here.

The format is based on [Keep a Changelog](https://keepachangelog.com/).

## [2.4.0] — 2026-07-01

Readable suggested BOM table.

### Added
- **`hardware/BOM.md`** — the bill of materials as a readable table with reference
  designators (Ref, Qty, Component, Value/Part, Example MPN, Package, Notes), clearly
  framed as a **suggested / reference setup, not a locked BOM**. Reference designators
  match the netlist; the BOM adds the extra decoupling caps, the cell, and the zebra
  connector a real build needs.
- **`hardware/kicad/bom-table.png`** — a styled rendered version of the table, and
  **`kicad/draw_bom.py`** to regenerate it from `bom.csv`.

## [2.3.0] — 2026-07-01

Clear placement diagram, honestly labelled.

### Added
- **`kicad/placement.png`** — a readable component-placement diagram with realistic
  part shapes (QFN packages, round coin cell, LCD with segment digits, crystal can,
  SWD pads), front/back, matched to the reference board's arrangement.
- **`kicad/draw_placement.py`** — renders it from the `.kicad_pcb`.

### Documented
- The kicad README now explains plainly that `placement.png` is a **suggested
  placement diagram — an illustration, not a manufactured PCB and not a routed
  board** — and why a Gerber never shows components (Gerbers describe only the bare
  board; a populated look requires a 3D render of a routed board). Same note added to
  `hardware/HARDWARE.md`.

## [2.2.0] — 2026-07-01

PCB placement revised to match the real production board.

### Changed
- **Placement now matches photographs of the actual board:** battery is an
  edge-mounted coin-cell clip at one end (not a centered holder); the IC cluster
  (MCU, NFC front-end, secure element, 32.768 kHz crystal can) sits at the other
  end; the "show" button is a through-hole dome on the front beside the LCD; the
  LCD is a chip-on-glass module filling ~60% of the front face. Added the board's
  **edge retention notches** to both the `.kicad_pcb` and the outline Gerber.
- Added an automatic overlap-resolution pass to `gen_pcb.py` so passive placement
  stays courtyard-clean while preserving the photo-matched big-part arrangement.
- Component values remain generic (real MPNs intentionally not published).

## [2.1.0] — 2026-07-01

PCB outline, placement, and mechanical Gerbers fitted to the OT1 enclosure.

### Added
- **`kicad/openT2OTP.kicad_pcb`** — a KiCad 7 board with the **outline, mounting
  holes, and full component placement**, sized to the real OT1 enclosure geometry
  (measured from the supplied STEP: 48×24 mm board, 4× M2 mounting holes at
  ±19.2/±7.3 mm boss positions). LCD on the front face; MCU, NFC, secure element,
  crystal, coin cell, SWD and passives on the back. Placement is overlap-checked
  and confined to the board.
- **`kicad/gen_pcb.py`** — the PCB generator (geometry derived from the enclosure).
- **`kicad/gen_gerber.py`** + **`kicad/gerbers/`** — a fabricable **board-outline
  Gerber** and Excellon **drill** file (validated: closed 48×24 mm profile, 4 holes).
- **`kicad/placement.png`** — front/back placement preview.

### Honest scope
- The board is **placement + mechanical outline only — not routed.** No copper
  traces, ground pour, or tuned antenna yet; the perimeter loop is placeholder
  geometry. The outline + drill Gerbers are fab-ready; the copper Gerbers are not,
  and must follow interactive routing + DRC in KiCad. Documented in
  `kicad/README.md`. This closes part of the long-standing "no routed board" gap —
  the mechanical/placement part — while being explicit about what routing remains.

## [2.0.0] — 2026-07-01

Renamed to **openT2OTP** and refreshed the brand.

### Changed
- **Project renamed openTOTP → openT2OTP** (T2 = Token2), because "openTOTP" was
  already taken. Applied across all file contents, the KiCad schematic/netlist
  filenames (`openT2OTP.kicad_sch`, `openT2OTP.net`), the source headers, and docs.
- **Logo & icon updated** (`docs/logo.svg`, `docs/icon.svg`): the countdown-ring
  token now carries a **T2 monogram** tying it to Token2, with a "TOKEN2" tagline.
  (Original mark, not Token2's trademarked logo — swap in the official icon if
  desired.)

### Note
- The only Python in the repo is two **hardware design tools**
  (`hardware/kicad/gen_schematic.py`, `hardware/antenna/tune.py`) — a schematic
  generator and an antenna-tuning calculator. **The firmware is C only**; no Python
  runs on the device or in the firmware build.

## [1.6.0] — 2026-07-01

Licensing headers and a second seed-security pass.

### Added
- **SPDX license headers on every source file.** All firmware `.c`/`.h` files carry
  `SPDX-License-Identifier: MIT` and `Copyright (c) 2020-2026 Token2 Sarl`; the
  hardware Python tools carry the CERN-OHL-P header. LICENSE and LICENSE-HARDWARE
  holder updated from the placeholder to **Token2 Sarl**.

### Changed / Fixed
- **Seed hygiene (defensive):** `cmd_seed()` now zeroizes the stored seed buffer
  before writing a new seed (no stale tail bytes from a longer previous seed) and
  scrubs the decrypted-seed scratch buffer off the stack after use.
- **Seed-protection docs expanded** after a second audit: documented that the
  display-path accessor copies the seed into MCU RAM (fine for a plain-MCU build,
  but for a secure-element build the HMAC must be computed *inside* the SE so the
  seed never enters RAM), plus the zeroization behavior. The accessor in `token2.c`
  now carries this SE caveat inline. Re-confirmed: the wire protocol has no
  seed-read path and no response emits seed bytes.

## [1.5.0] — 2026-07-01

Seed-protection documentation, logo, and naming note.

### Added
- **Seed protection section** in `docs/SECURITY.md` making the two guarantees
  explicit and separate: (1) the seed is **write-only over the wire** — the
  protocol has no read-seed command and no response ever contains seed bytes
  (a hard property of the dispatcher; verified by inspection); (2) **extraction
  resistance depends on where the seed is stored**, with a concrete table:
  Pico / plain MCU flash = assume extractable; debug-locked MCU = partial; discrete
  secure element (SE050 / ATECC608) = not extractable, especially with a
  non-exportable key and HMAC computed inside the SE. `hardware/HARDWARE.md`
  strengthened to match.
- **Project logo** (`docs/logo.svg`) and icon (`docs/icon.svg`): a TOTP countdown
  ring around a 7-segment digit on a keyfob silhouette. Added to the README header.

### Changed
- **Naming note** added to the README: "openT2OTP" is the name chosen for the
  open-source release; the firmware was developed internally under a different
  codename. The name is new; the core is not.

## [1.4.0] — 2026-07-01

Real production provenance, and the SHA-256 path made real.

### Added
- **HMAC-SHA256 (`algo=2`) fully implemented** in the TOTP path. Previously the
  display path only did SHA1 and silently ignored the configured algorithm; the
  config already stored `hmac_algo`, but generation didn't honor it. Added a
  SHA-256 core and `totp_now_algo(...)`; `totp_now()` remains a SHA1 wrapper.
  Verified against the RFC 6238 Appendix B SHA-256 vectors (46119246 / 68084774 /
  90698825) alongside the existing SHA-1 vectors.

### Changed
- **Provenance corrected across the docs.** This is documented as the **actual
  firmware core our tokens run**, now open-sourced — not a clean-room
  reconstruction. Added project history: core **finalized in 2020**, most recent
  change in **2025** (removal of the wrong-key lockout), and it is exactly what
  current hardware runs. Updated the root README, `firmware/README.md`, and
  `docs/SECURITY.md` (lockout history).
- **Hardware sourcing note reframed:** components were **ordered specifically for
  this core**; research indicates off-the-shelf parts should also work; we'll
  update for small changes, and community reports of incompatibilities are welcome.
  Updated `hardware/HARDWARE.md`, the README, and `CONTRIBUTING.md`.

## [1.3.0] — 2026-07-01

Removed the Raspberry Pi Pico port.

An earlier revision added a Pico + Waveshare-LCD dev-board port as a
zero-sourcing way to run the firmware. It was removed: re-implementing the
display/transport on a Pico (and the MicroPython smoke test that came with it)
was not reproducible in the same sense as the rest of the project — a Pico has
no secure element and no battery, so it could never be the offline token this
design is about, and it muddied what the repo demonstrates. The project is
back to its two intended parts: the verified C firmware and the secure-element
hardware reference.

### Removed
- `firmware/ports/pico/` (Pico HAL, pixel display, USB-serial transport, optional
  USB-keyboard typing, MicroPython smoke test) and the `pico-render` / `pico-kbd`
  make targets and CI steps.

### Kept
- `make provision` — the full challenge→auth→config→seed flow verified against the
  RFC 6238 vector. It is transport-agnostic (not Pico-specific) and remains a core
  test.
- The **sourcing note**: production parts are proven but not always easily
  sourceable (some are factory-tailored equivalents); the BOM lists mainstream
  buy-anywhere equivalents.

## [1.1.0] — 2026-07-01

Correctness pass and hardware design files.

### Fixed
- **Seed length cap.** `cmd_seed()` rejected seeds whose ciphertext exceeded 48
  bytes, which wrongly refused seeds of 48–63 bytes (a 63-byte seed frames to a
  64-byte ciphertext). Cap corrected to 64. All seed lengths 1..63, in both the
  general and 32-byte-special framings, now round-trip exactly (new `make seed`).

### Added
- `make seed` — seed framing round-trip test across lengths 1..63 and both forms.
- `make slcd` — segment-LCD driver test with an ASCII render of the digits, plus
  host stubs for the three `hal_slcd_*` hooks (reference for the display port).
- `make all` — run every verification target.
- Hardware design files: machine-readable `bom.csv`, KiCad connectivity schematic
  and netlist, `PINMAP.md`, and an antenna coil/tuning reference.

### Changed
- Battery life corrected throughout to **5–8 years (model-dependent)** with the
  supporting current/capacity math, replacing the earlier ~1-year figure.
- Framing reworded to lead with the **wire protocol**: the firmware implements the
  documented protocol and interoperates with any conformant host; `token2_config.py`
  is cited as one such open host rather than the thing being "answered".
- Clarified `display_timeout` wire values (0..3) vs the host `--sleep` argument
  indexing (1..4).

## [1.0.0] — 2026-07-01

Initial public release of the production firmware core (finalized 2020).

### Added
- Device-side firmware implementing the Token2 single-profile TOTP wire protocol
  (get-info, SM4 challenge/response auth, MAC-protected seed and config writes).
- SM4 (GB/T 32907) implementation with GM/T 0002 known-answer test.
- RFC 6238 TOTP generation (HMAC-SHA1) with RFC test-vector verification.
- Segment-LCD display driver with a portable 7-segment font and a board-specific
  segment-map hook.
- NFC transport shim for secure-element applet or MCU ISO-DEP integration.
- Hardware reference: LCD wiring, costed BOM, PCB floorplan, antenna and casing
  notes. Keyfob-dongle main form factor, card documented as a variation.
- Documentation: protocol reference, security/threat model (TOTP vs FIDO2),
  porting guide.
- CI running all three verification targets on every change.

### Notes
- TOTP is not phishing-resistant; use FIDO2 / WebAuthn where phishing resistance
  is required. See `docs/SECURITY.md`.
- This initial release shipped the SHA-1 display path; full HMAC-SHA256 (config
  `algo=2`) was completed later — see 1.4.0.

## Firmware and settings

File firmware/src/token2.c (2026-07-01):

/* SPDX-License-Identifier: MIT
 * Copyright (c) 2020-2026 Token2 Sarl
 *
 * Part of openT2OTP - the open-source release of the firmware core that runs
 * Token2's programmable TOTP hardware tokens. See LICENSE and README.md.
 */
/* token2.c - device-side firmware for the Token2 single-profile programmable
 * TOTP token. Answers exactly the APDUs that token2_config.py sends.
 *
 * Command set (from PROTOCOL.md):
 *   Plain  (CLA 0x80): 0x41 get-info, 0x4B get-challenge, 0xCE auth-finish
 *   Secure (CLA 0x84): 0xC5 write-seed, 0xD4 write-config   (4-byte CBC-MAC)
 */
#include "token2.h"
#include "sm4.h"
#include "token2_hal.h"
#include <string.h>

/* device key: 8A D2 06 88 3C A3 69 48 2A B2 71 82 B6 E8 32 24
 * Public and identical on every device — this is intentional for the Token2
 * protocol (the value is documented). Where it lives doesn't matter because it
 * is not a secret. To make it a per-device SECRET for a fork, don't edit this
 * constant: source the key from the HAL (e.g. hal_get_device_key()) backed by
 * secure-element/protected-flash/PUF storage, and add retry throttling. See
 * docs/SECURITY.md ("The device key" and "Retry / lockout behaviour"). */
const uint8_t TOKEN2_DEVICE_SM4_KEY[16] = {
    0x8A,0xD2,0x06,0x88,0x3C,0xA3,0x69,0x48,
    0x2A,0xB2,0x71,0x82,0xB6,0xE8,0x32,0x24
};

/* NVM addresses */
#define NV_STATE_ADDR 0x0000

static token2_state_t S;

/* --- session (RAM only) auth state --- */
static uint8_t g_challenge[8];
static uint8_t g_have_challenge;
static uint8_t g_authed;

static void persist(void){ hal_nvm_write(NV_STATE_ADDR,&S,sizeof S); }

void token2_init(void){
    if(hal_nvm_read(NV_STATE_ADDR,&S,sizeof S)!=0 || S.serial_len==0){
        /* first boot / blank part: install factory defaults */
        memset(&S,0,sizeof S);
        /* OTPC-P2-i prefix 8659622 by default */
        memcpy(S.serial,"86596220000001",14); S.serial_len=14;
        S.hmac_algo=1; S.time_step=0x1E; S.display_timeout=1;
        S.restricted_sync=1;
        persist();
    }
}

/* Read the provisioned TOTP parameters, for on-device code generation/display.
 * Returns 1 if a seed is present, 0 otherwise. Never exposes the seed over the
 * wire protocol -- this is an internal accessor for the display path only.
 *
 * SECURE-ELEMENT NOTE: this default implementation copies the raw seed into the
 * caller's buffer (i.e. into MCU RAM). That is fine for a plain-MCU build, but on
 * a secure-element build it defeats the SE: the seed should never leave the SE.
 * For an SE build, do NOT return raw seed bytes here -- instead compute the HMAC
 * inside the SE and have the display path call an SE HMAC routine, so the seed is
 * never present in MCU memory. See docs/SECURITY.md ("Seed protection"). */
int token2_get_totp_params(uint8_t *seed, uint8_t *seed_len,
                           uint8_t *algo, uint8_t *step){
    if(seed && S.seed_len) memcpy(seed, S.seed, S.seed_len);
    if(seed_len) *seed_len = S.seed_len;
    if(algo)     *algo     = S.hmac_algo;
    if(step)     *step     = S.time_step;
    return S.seed_len ? 1 : 0;
}

/* helper: append SW to resp */
static size_t put_sw(uint8_t *resp, size_t n, uint16_t sw){
    resp[n]=(uint8_t)(sw>>8); resp[n+1]=(uint8_t)sw; return n+2;
}

/* ---- 0x41 get info -------------------------------------------------------
 * layout: 3 hdr | 1 serial_len | N serial | 2 sep | 4 utc BE  */
static size_t cmd_info(uint8_t *resp, size_t cap){
    size_t n=0; uint32_t t=hal_rtc_get();
    if(cap < (size_t)(3+1+S.serial_len+2+4+2)) return put_sw(resp,0,SW_WRONG_LEN);
    resp[n++]=0x00; resp[n++]=0x00; resp[n++]=0x00;        /* header (opaque) */
    resp[n++]=S.serial_len;
    memcpy(resp+n,S.serial,S.serial_len); n+=S.serial_len;
    resp[n++]=0x00; resp[n++]=0x00;                        /* separator */
    resp[n++]=t>>24; resp[n++]=t>>16; resp[n++]=t>>8; resp[n++]=t;
    return put_sw(resp,n,SW_OK);
}

/* ---- 0x4B get challenge --------------------------------------------------*/
static size_t cmd_challenge(uint8_t *resp, size_t cap){
    if(cap<10) return put_sw(resp,0,SW_WRONG_LEN);
    hal_rng(g_challenge,8);
    g_have_challenge=1; g_authed=0;
    memcpy(resp,g_challenge,8);
    return put_sw(resp,8,SW_OK);
}

/* ---- 0xCE auth finish ----------------------------------------------------
 * host sends SM4(challenge||8 zero bytes). Verify. */
static size_t cmd_auth_finish(const uint8_t *data, size_t dlen, uint8_t *resp){
    uint8_t plain[16], expect[16];
    if(S.key_locked)              return put_sw(resp,0,SW_AUTH_LOCK);
    if(!g_have_challenge||dlen!=16) return put_sw(resp,0,SW_DATA_NG);
    memcpy(plain,g_challenge,8);
    memset(plain+8,0,8);
    sm4_ecb_encrypt(TOKEN2_DEVICE_SM4_KEY,plain,expect,1);
    if(hal_ct_memcmp(expect,data,16)!=0){
        g_have_challenge=0;
        return put_sw(resp,0,SW_AUTH_LOCK);
    }
    g_authed=1; g_have_challenge=0;
    return put_sw(resp,0,SW_OK);
}

/* Verify the 4-byte MAC trailing a CLA 0x84 command.
 * MAC input = [0x80,INS,P1,P2,Lc'] || body, Lc'=body length (no MAC). */
static int mac_ok(uint8_t ins,uint8_t p1,uint8_t p2,
                  const uint8_t *body,size_t blen,const uint8_t *mac){
    uint8_t buf[256]; uint8_t got[4];
    if(blen+5>sizeof buf) return 0;
    buf[0]=0x80; buf[1]=ins; buf[2]=p1; buf[3]=p2; buf[4]=(uint8_t)blen;
    memcpy(buf+5,body,blen);
    sm4_cbc_mac(TOKEN2_DEVICE_SM4_KEY,buf,blen+5,got);
    return hal_ct_memcmp(got,mac,4)==0;
}

/* ---- 0xC5 write seed -----------------------------------------------------
 * body = SM4-ECB(seed with 9797-1 padding); trailing 4-byte MAC.
 * We decrypt to recover the seed then strip padding. */
static void sm4_ecb_decrypt_block(const uint8_t key[16],const uint8_t in[16],uint8_t out[16]){
    /* SM4 decryption = encryption with reversed round keys */
    uint32_t rk[32],rrk[32]; int i;
    sm4_key_schedule(key,rk);
    for(i=0;i<32;i++) rrk[i]=rk[31-i];
    sm4_ecb_block(rrk,in,out);
}
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

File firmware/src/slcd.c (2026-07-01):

/* SPDX-License-Identifier: MIT
 * Copyright (c) 2020-2026 Token2 Sarl
 *
 * Part of openT2OTP - the open-source release of the firmware core that runs
 * Token2's programmable TOTP hardware tokens. See LICENSE and README.md.
 */
/* slcd.c - segment LCD driver for a 6-digit 7-segment TOTP display.
 *
 * Targets the SAM L22 on-chip SLCD controller (register-level writes go in the
 * HAL below). The panel is a 6-digit static/multiplexed 7-seg glass; each digit
 * is 7 segments (a..g) plus optional decimal point. We use a 4-COM x N-SEG
 * layout typical of a 1/4-duty, 1/3-bias glass:
 *
 *      a
 *    -----
 *  f |   | b
 *    | g |
 *    -----
 *  e |   | c
 *    |   |
 *    -----
 *      d
 *
 * On the SAM L22 you assign each segment to a (COM, SEG) pin pair in the glass
 * datasheet's pinout table, then set/clear the matching bit in the SLCD frame
 * buffer. Below we keep a portable segment bitmap and delegate the actual
 * COM/SEG bit placement to hal_slcd_set_digit(), which you fill in from your
 * glass's pin map. */
#include "slcd.h"
#include "token2_hal.h"

/* 7-seg font, bit order: gfedcba (bit0=a .. bit6=g) */
static const uint8_t FONT[10] = {
    0x3F, /*0*/ 0x06, /*1*/ 0x5B, /*2*/ 0x4F, /*3*/ 0x66, /*4*/
    0x6D, /*5*/ 0x7D, /*6*/ 0x07, /*7*/ 0x7F, /*8*/ 0x6F  /*9*/
};

/* Provided by the SAM L22 HAL: write the 7 segment bits for one digit position
 * into the SLCD frame buffer using the glass's COM/SEG mapping. */
extern void hal_slcd_set_digit(int position, uint8_t seg_bits);
extern void hal_slcd_commit(void);      /* latch frame buffer to the panel */
extern void hal_slcd_blank(void);       /* all segments off (sleep) */

void slcd_show_code(uint32_t code, int digits){
    int i; uint32_t v=code;
    /* right-aligned, leading zeros (standard for OTP tokens) */
    for(i=digits-1;i>=0;i--){
        hal_slcd_set_digit(i, FONT[v%10]);
        v/=10;
    }
    /* blank any unused positions to the left (max 6) */
    for(i=digits;i<6;i++) hal_slcd_set_digit(i,0x00);
    hal_slcd_commit();
}

void slcd_blank(void){ hal_slcd_blank(); }

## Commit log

2026-07-01 openT2OTP: initial public release
    [bom.csv, openT2OTP.kicad_pcb, openT2OTP.kicad_sch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]
2026-07-01 Add board layout section to README
    Added board layout section with component placement image.
2026-07-01 Update security guidelines for testing devices
